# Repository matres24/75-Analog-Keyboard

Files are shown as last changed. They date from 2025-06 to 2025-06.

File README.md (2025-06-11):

# 75%-Analog-Keyboard
A custom-built mechanical keyboard featuring Hall effect sensors for analog key press detection. This project uses DRV5055A4 Hall sensors, magnets mounted in keycaps, and a CD74HC4067 multiplexer controlled by a microcontroller. Each key press is measured as a variable voltage, enabling analog input functionality. RGB LEDs (WS2812B) provide per-key lighting. This project is meant to fit into Monsgeek M1 case.

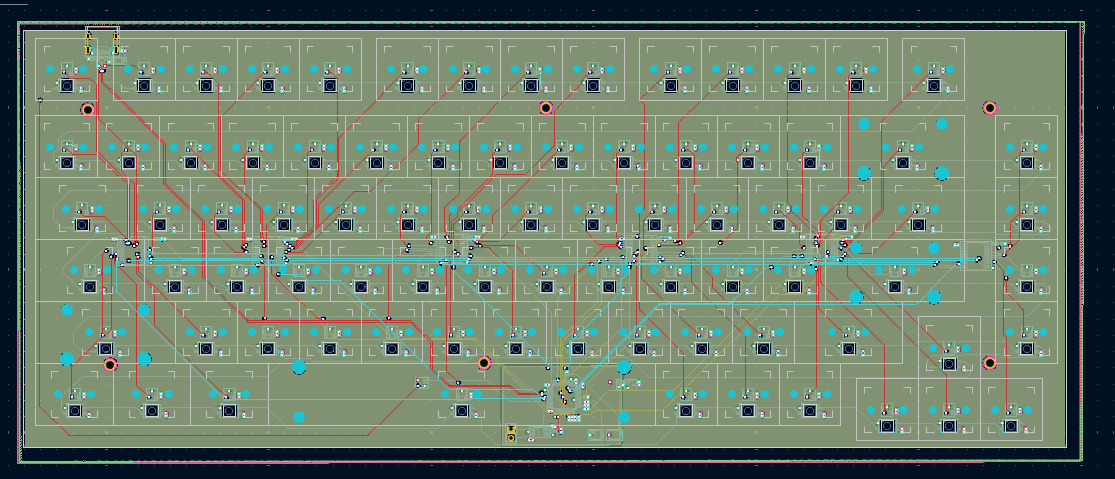
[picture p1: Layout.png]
Layout


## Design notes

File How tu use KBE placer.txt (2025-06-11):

also regarding your issue with the kbplacer plugin, a workflow that I like to use is:
use hierarchial sheets, one for each sensor
load in one of the footprints to kbplacer
disable diode auto-placement, disable auto-routing, remove "additional elements"
run the plugin
route the first sensor to its decoupling capacitors
use the "replicate layouts" plugin to replicate the placement of the remaining components and the routing

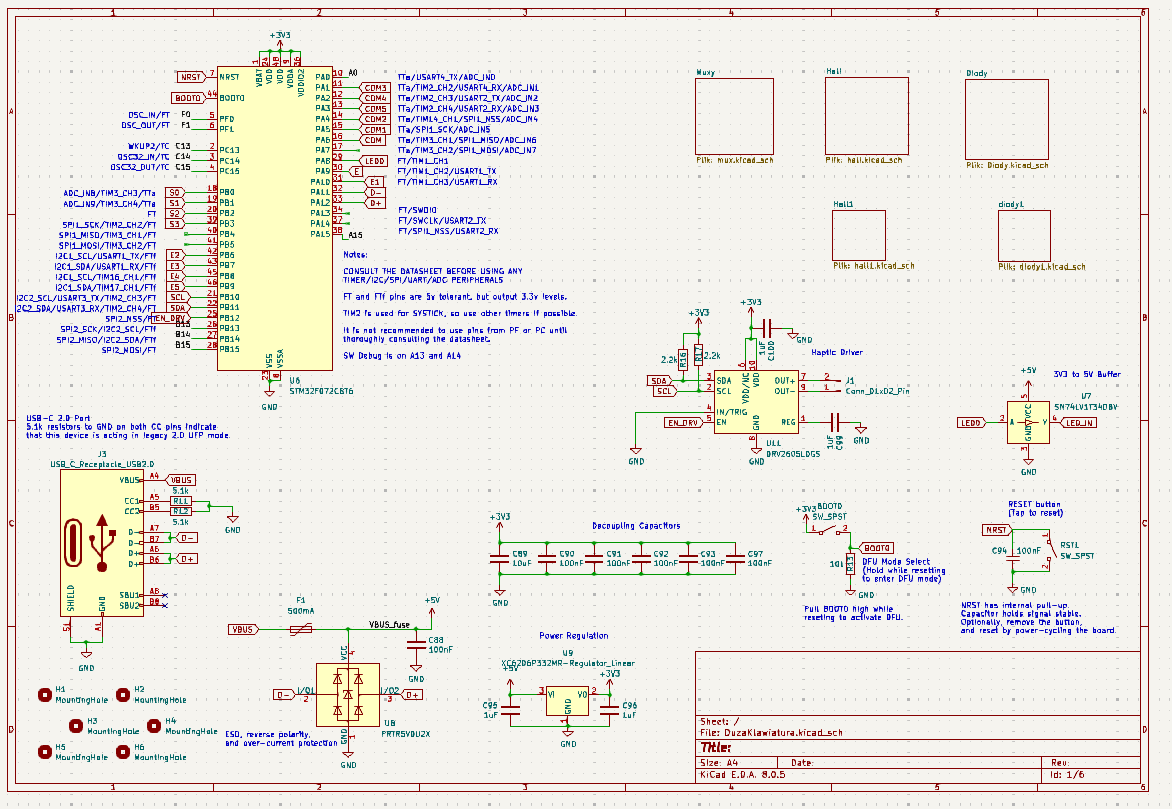
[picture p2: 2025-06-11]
Schematic.png

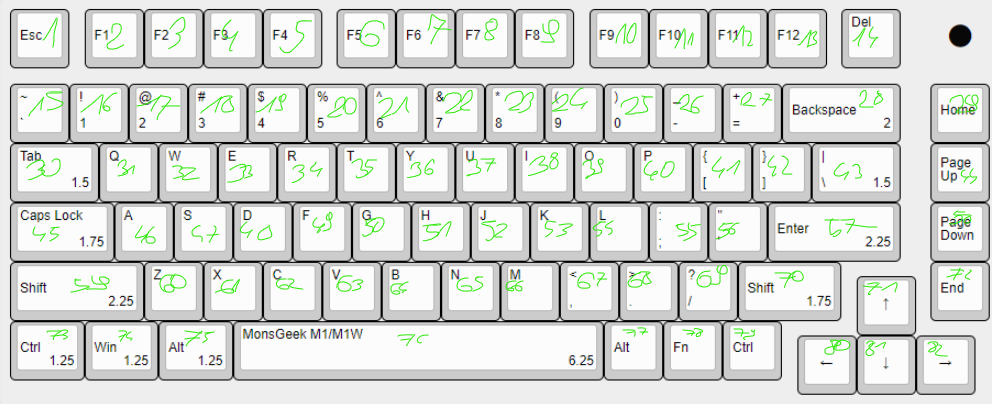
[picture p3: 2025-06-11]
Keylayout.png

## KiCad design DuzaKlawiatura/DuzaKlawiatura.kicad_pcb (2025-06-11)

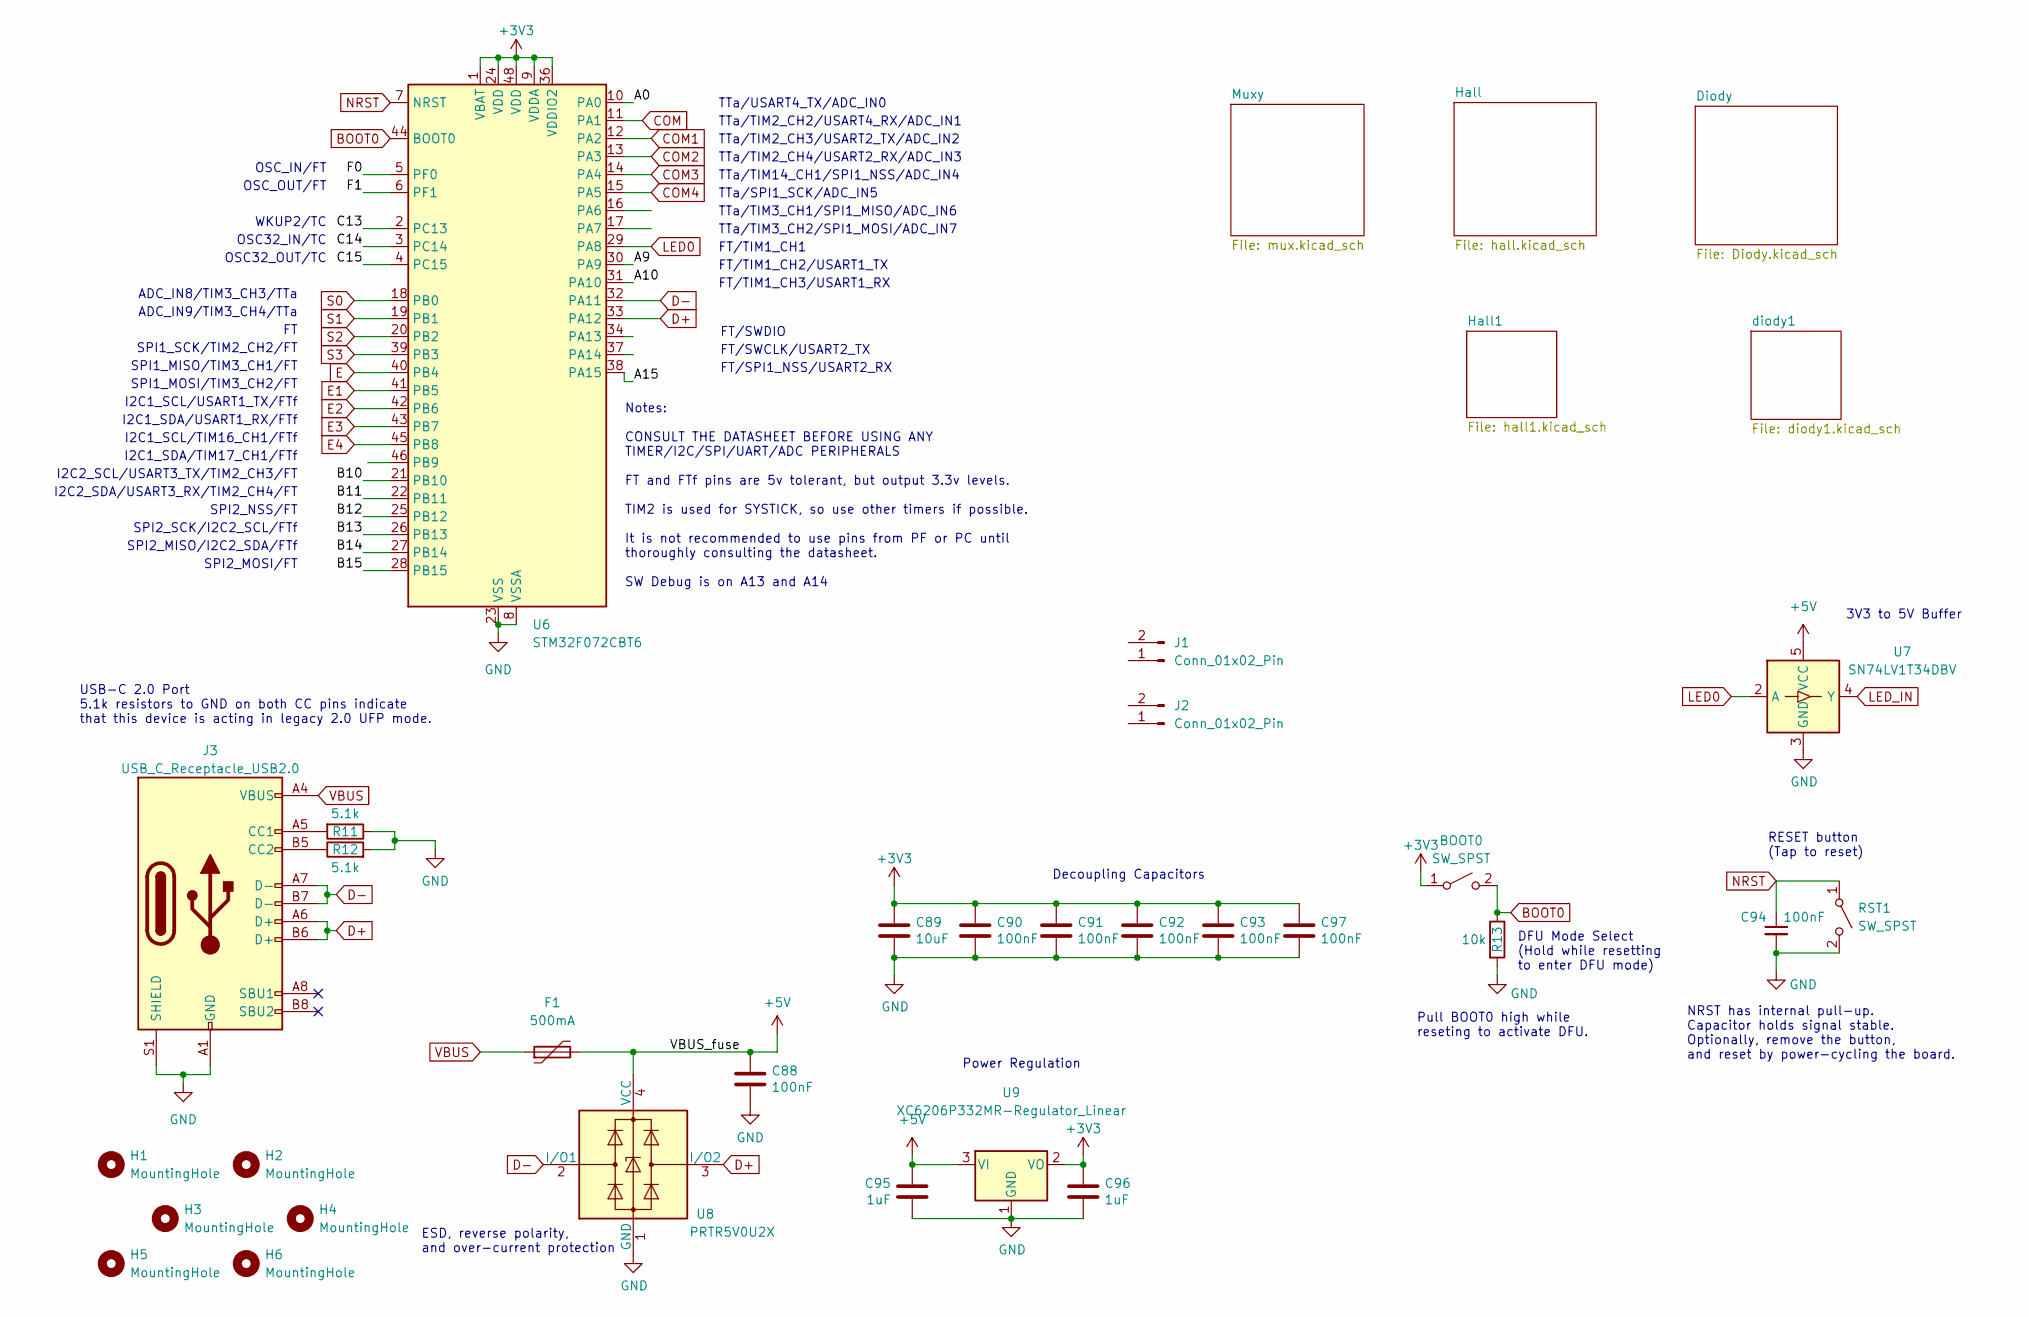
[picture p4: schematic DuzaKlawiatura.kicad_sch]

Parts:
BOOT0: SW_SPST; SW_SPST_B3U-1000P
C88, C90, C91, C92, C93, C94, C97: 100nF; C_0402_1005Metric; LCSC C307331
C89: 10uF; C_0603_1608Metric; LCSC C307331
C95, C96: 1uF; C_0402_1005Metric; LCSC C307331
F1: 500mA; Fuse_1206_3216Metric; LCSC C135341
H1, H2, H3, H4, H5, H6: MountingHole; MountingHole_2.2mm_M2_ISO7380_Pad
J1, J2: Conn_01x02_Pin; MountingHole_2.2mm_M2_ISO7380_Pad
J3: USB_C_Receptacle_USB2.0; USB_C_Receptacle_HRO_TYPE-C-31-M-12; JlcRotOffset 180
R11, R12: 5.1k; R_0402_1005Metric
R13: 10k; R_0402_1005Metric
RST1: SW_SPST; SW_SPST_B3U-1000P
U6: STM32F072CBT6; LQFP-48_7x7mm_P0.5mm; JlcRotOffset 90
U7: SN74LV1T34DBV; SOT-23-5
U8: PRTR5V0U2X; SOT-143; LCSC C2827688
U9: XC6206P332MR-Regulator_Linear; SOT-23; LCSC C5446

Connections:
+3V3: BOOT0.1 (A), C89.1, C90.1, C91.1, C92.1, C93.1, C96.1, C97.1, U6.1 (VBAT), U6.9 (VDDA), U6.24 (VDD), U6.36 (VDDIO2), U6.48 (VDD), U9.2 (VO); also elsewhere on the board
+5V: C88.1, C95.1, F1.2, U7.5 (VCC), U8.4 (VCC), U9.3 (VI); also elsewhere on the board
/A0: U6.10 (PA0)
/A9: U6.30 (PA9)
/A10: U6.31 (PA10)
/A15: U6.38 (PA15)
/B10: U6.21 (PB10)
/B11: U6.22 (PB11)
/B12: U6.25 (PB12)
/B13: U6.26 (PB13)
/B14: U6.27 (PB14)
/B15: U6.28 (PB15)
/C13: U6.2 (PC13)
/C14: U6.3 (PC14)
/C15: U6.4 (PC15)
/F0: U6.5 (PF0)
/F1: U6.6 (PF1)
BOOT0: BOOT0.2 (B), R13.1, U6.44 (BOOT0); also elsewhere on the board
COM: U6.11 (PA1); also elsewhere on the board
COM1: U6.12 (PA2); also elsewhere on the board
COM2: U6.13 (PA3); also elsewhere on the board
COM3: U6.14 (PA4); also elsewhere on the board
COM4: U6.15 (PA5); also elsewhere on the board
D+: J3.A6 (D+), J3.B6 (D+), U6.33 (PA12), U8.3 (I/O2)
D-: J3.A7 (D-), J3.B7 (D-), U6.32 (PA11), U8.2 (I/O1)
E: U6.40 (PB4); also elsewhere on the board
E1: U6.41 (PB5); also elsewhere on the board
E2: U6.42 (PB6); also elsewhere on the board
E3: U6.43 (PB7); also elsewhere on the board
E4: U6.45 (PB8); also elsewhere on the board
GND: C88.2, C89.2, C90.2, C91.2, C92.2, C93.2, C94.2, C95.2, C96.2, C97.2, J3.A1 (GND), J3.A12 (GND), J3.B1 (GND), J3.B12 (GND), J3.S1 (SHIELD), R11.1, R12.2, R13.2, RST1.2 (B), U6.8 (VSSA), U6.23 (VSS), U6.35 (VSS), U6.47 (VSS), U7.3 (GND), U8.1 (GND), U9.1 (GND); also elsewhere on the board
LED0: U6.29 (PA8), U7.2 (A)
LED_IN: U7.4 (Y); also elsewhere on the board
NRST: C94.1, RST1.1 (A), U6.7 (NRST)
unnamed: J3.A5 (CC1), R11.2
unnamed: J3.B5 (CC2), R12.1
S0: U6.18 (PB0); also elsewhere on the board
S1: U6.19 (PB1); also elsewhere on the board
S2: U6.20 (PB2); also elsewhere on the board
S3: U6.39 (PB3); also elsewhere on the board
VBUS: F1.1, J3.A4 (VBUS), J3.A9 (VBUS), J3.B4 (VBUS), J3.B9 (VBUS)

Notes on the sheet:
TTa/SPI1_SCK/ADC_IN5
SPI2_MOSI/FT
TTa/USART4_TX/ADC_IN0
ADC_IN9/TIM3_CH4/TTa
TTa/TIM3_CH1/SPI1_MISO/ADC_IN6
3V3 to 5V Buffer
I2C1_SDA/TIM17_CH1/FTf
WKUP2/TC
Notes: CONSULT THE DATASHEET BEFORE USING ANY TIMER/I2C/SPI/UART/ADC PERIPHERALS FT and FTf pins are 5v tolerant, but output 3.3v levels. TIM2 is used for SYSTICK, so use other timers if possible. It is not recommended to use pins from PF or PC until thoroughly consulting the datasheet. SW Debug is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
TTa/TIM2_CH3/USART2_TX/ADC_IN2
I2C2_SDA/USART3_RX/TIM2_CH4/FT
SPI2_NSS/FT
TTa/TIM3_CH2/SPI1_MOSI/ADC_IN7
SPI1_SCK/TIM2_CH2/FT
TTa/TIM2_CH2/USART4_RX/ADC_IN1
Decoupling Capacitors
FT/TIM1_CH2/USART1_TX
Pull BOOT0 high while reseting to activate DFU.
SPI2_SCK/I2C2_SCL/FTf
FT/SPI1_NSS/USART2_RX
SPI1_MISO/TIM3_CH1/FT
FT/SWDIO
ADC_IN8/TIM3_CH3/TTa
DFU Mode Select (Hold while resetting to enter DFU mode)
I2C1_SCL/TIM16_CH1/FTf
FT/TIM1_CH1
ESD, reverse polarity, and over-current protection
OSC_OUT/FT
NRST has internal pull-up. Capacitor holds signal stable. Optionally, remove the button, and reset by power-cycling the board.
I2C1_SCL/USART1_TX/FTf
I2C1_SDA/USART1_RX/FTf
SPI1_MOSI/TIM3_CH2/FT
Power Regulation
FT/TIM1_CH3/USART1_RX
USB-C 2.0 Port 5.1k resistors to GND on both CC pins indicate that this device is acting in legacy 2.0 UFP mode.
SPI2_MISO/I2C2_SDA/FTf
OSC_IN/FT
RESET button (Tap to reset)
I2C2_SCL/USART3_TX/TIM2_CH3/FT
OSC32_IN/TC

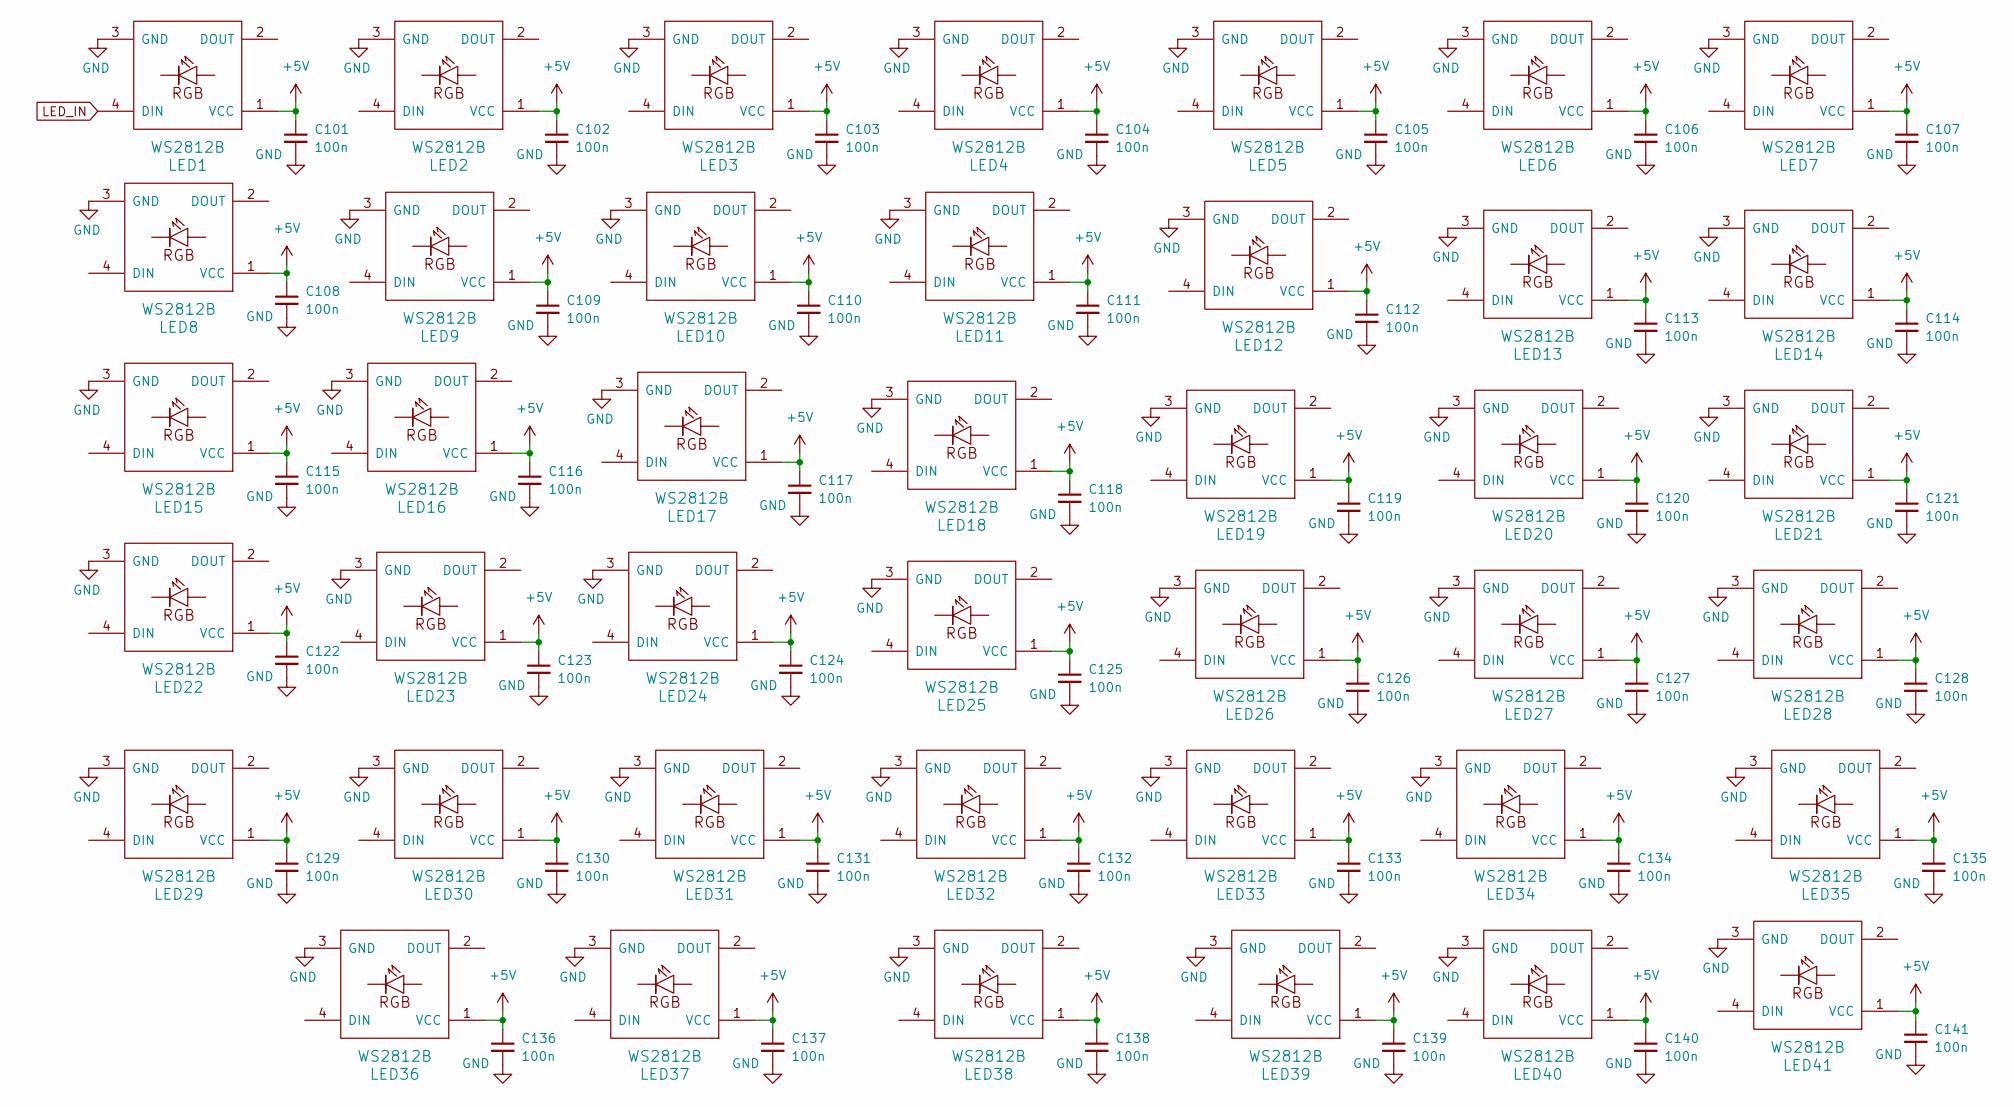
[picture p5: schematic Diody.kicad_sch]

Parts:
C101, C102, C103, C104, C105, C106, C107, C108, C109, C110, C111, C112, C113, C114, C115, C116, C117, C118, C119, C120, C121, C122, C123, C124, C125, C126, C127, C128, C129, C130, C131, C132, C133, C134, C135, C136, C137, C138, C139, C140, C141: 100n; C_0402_1005Metric
LED1, LED2, LED3, LED4, LED5, LED6, LED7, LED8, LED9, LED10, LED11, LED12, LED13, LED14, LED15, LED16, LED17, LED18, LED19, LED20, LED21, LED22, LED23, LED24, LED25, LED26, LED27, LED28, LED29, LED30, LED31, LED32, LED33, LED34, LED35, LED36, LED37, LED38, LED39, LED40, LED41: WS2812B; MX-LED_WS2812B_wide

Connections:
+5V: C101.1, C102.1, C103.1, C104.1, C105.1, C106.1, C107.1, C108.1, C109.1, C110.1, C111.1, C112.1, C113.1, C114.1, C115.1, C116.1, C117.1, C118.1, C119.1, C120.1, C121.1, C122.1, C123.1, C124.1, C125.1, C126.1, C127.1, C128.1, C129.1, C130.1, C131.1, C132.1, C133.1, C134.1, C135.1, C136.1, C137.1, C138.1, C139.1, C140.1, C141.1, LED1.1 (VCC), LED2.1 (VCC), LED3.1 (VCC), LED4.1 (VCC), LED5.1 (VCC), LED6.1 (VCC), LED7.1 (VCC), LED8.1 (VCC), LED9.1 (VCC), LED10.1 (VCC), LED11.1 (VCC), LED12.1 (VCC), LED13.1 (VCC), LED14.1 (VCC), LED15.1 (VCC), LED16.1 (VCC), LED17.1 (VCC), LED18.1 (VCC), LED19.1 (VCC), LED20.1 (VCC), LED21.1 (VCC), LED22.1 (VCC), LED23.1 (VCC), LED24.1 (VCC), LED25.1 (VCC), LED26.1 (VCC), LED27.1 (VCC), LED28.1 (VCC), LED29.1 (VCC), LED30.1 (VCC), LED31.1 (VCC), LED32.1 (VCC), LED33.1 (VCC), LED34.1 (VCC), LED35.1 (VCC), LED36.1 (VCC), LED37.1 (VCC), LED38.1 (VCC), LED39.1 (VCC), LED40.1 (VCC), LED41.1 (VCC); also elsewhere on the board
GND: C101.2, C102.2, C103.2, C104.2, C105.2, C106.2, C107.2, C108.2, C109.2, C110.2, C111.2, C112.2, C113.2, C114.2, C115.2, C116.2, C117.2, C118.2, C119.2, C120.2, C121.2, C122.2, C123.2, C124.2, C125.2, C126.2, C127.2, C128.2, C129.2, C130.2, C131.2, C132.2, C133.2, C134.2, C135.2, C136.2, C137.2, C138.2, C139.2, C140.2, C141.2, LED1.3 (GND), LED2.3 (GND), LED3.3 (GND), LED4.3 (GND), LED5.3 (GND), LED6.3 (GND), LED7.3 (GND), LED8.3 (GND), LED9.3 (GND), LED10.3 (GND), LED11.3 (GND), LED12.3 (GND), LED13.3 (GND), LED14.3 (GND), LED15.3 (GND), LED16.3 (GND), LED17.3 (GND), LED18.3 (GND), LED19.3 (GND), LED20.3 (GND), LED21.3 (GND), LED22.3 (GND), LED23.3 (GND), LED24.3 (GND), LED25.3 (GND), LED26.3 (GND), LED27.3 (GND), LED28.3 (GND), LED29.3 (GND), LED30.3 (GND), LED31.3 (GND), LED32.3 (GND), LED33.3 (GND), LED34.3 (GND), LED35.3 (GND), LED36.3 (GND), LED37.3 (GND), LED38.3 (GND), LED39.3 (GND), LED40.3 (GND), LED41.3 (GND); also elsewhere on the board
LED_IN: LED1.4 (DIN); also elsewhere on the board

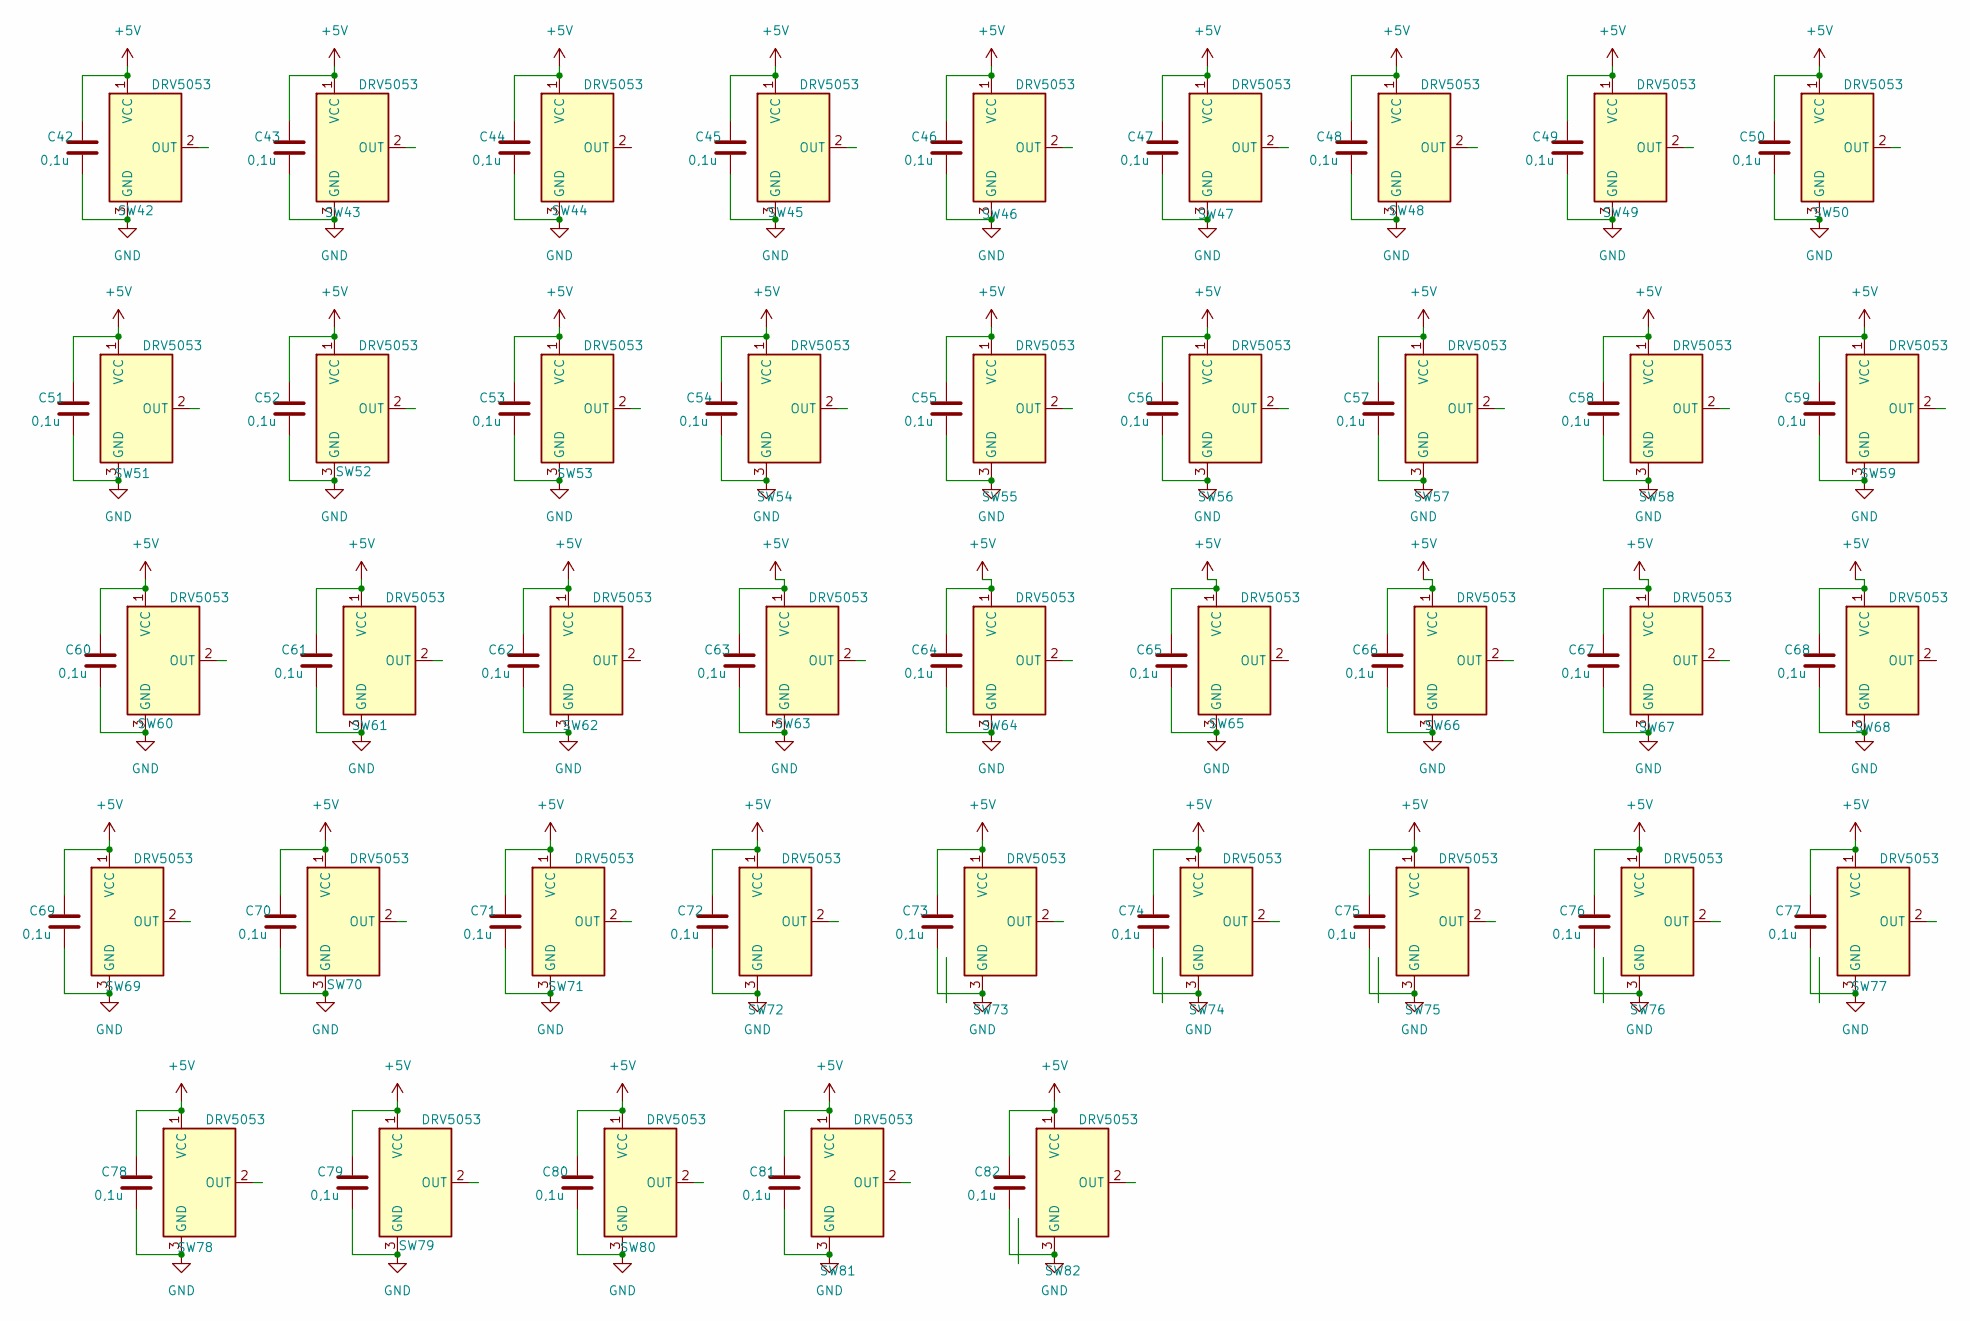
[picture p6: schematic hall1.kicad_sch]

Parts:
C42, C43, C44, C45, C46, C47, C48, C49, C50, C51, C52, C53, C54, C55, C56, C57, C58, C59, C60, C61, C62, C63, C64, C65, C66, C67, C68, C69, C70, C71, C72, C73, C74, C75, C76, C77, C78, C79, C80, C81, C82: 0,1u; C_0402_1005Metric
SW42, SW44, SW46, SW47, SW48, SW49, SW50, SW51, SW52, SW53, SW54, SW55, SW56, SW58, SW60, SW61, SW62, SW63, SW64, SW65, SW66, SW67, SW68, SW69, SW71, SW72, SW77, SW78, SW79, SW80, SW81, SW82: DRV5053; MX-Analog-1U
SW43: DRV5053; MX-Analog-1.5U
SW45, SW70: DRV5053; MX-Analog-1.75U
SW57, SW59: DRV5053; MX-Analog-2.25U
SW73, SW74, SW75: DRV5053; MX-Analog-1.25U
SW76: DRV5053; MX-Analog-6.25U-ReversedStabilizers

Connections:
+5V: C42.1, C43.1, C44.1, C45.1, C46.1, C47.1, C48.1, C49.1, C50.1, C51.1, C52.1, C53.1, C54.1, C55.1, C56.1, C57.1, C58.1, C59.1, C60.1, C61.1, C62.1, C63.1, C64.1, C65.1, C66.1, C67.1, C68.1, C69.1, C70.1, C71.1, C72.1, C73.1, C74.1, C75.1, C76.1, C77.1, C78.1, C79.1, C80.1, C81.1, C82.1, SW42.1 (VCC), SW43.1 (VCC), SW44.1 (VCC), SW45.1 (VCC), SW46.1 (VCC), SW47.1 (VCC), SW48.1 (VCC), SW49.1 (VCC), SW50.1 (VCC), SW51.1 (VCC), SW52.1 (VCC), SW53.1 (VCC), SW54.1 (VCC), SW55.1 (VCC), SW56.1 (VCC), SW57.1 (VCC), SW58.1 (VCC), SW59.1 (VCC), SW60.1 (VCC), SW61.1 (VCC), SW62.1 (VCC), SW63.1 (VCC), SW64.1 (VCC), SW65.1 (VCC), SW66.1 (VCC), SW67.1 (VCC), SW68.1 (VCC), SW69.1 (VCC), SW70.1 (VCC), SW71.1 (VCC), SW72.1 (VCC), SW73.1 (VCC), SW74.1 (VCC), SW75.1 (VCC), SW76.1 (VCC), SW77.1 (VCC), SW78.1 (VCC), SW79.1 (VCC), SW80.1 (VCC), SW81.1 (VCC), SW82.1 (VCC); also elsewhere on the board
GND: C42.2, C43.2, C44.2, C45.2, C46.2, C47.2, C48.2, C49.2, C50.2, C51.2, C52.2, C53.2, C54.2, C55.2, C56.2, C57.2, C58.2, C59.2, C60.2, C61.2, C62.2, C63.2, C64.2, C65.2, C66.2, C67.2, C68.2, C69.2, C70.2, C71.2, C72.2, C73.2, C74.2, C75.2, C76.2, C77.2, C78.2, C79.2, C80.2, C81.2, C82.2, SW42.3 (GND), SW43.3 (GND), SW44.3 (GND), SW45.3 (GND), SW46.3 (GND), SW47.3 (GND), SW48.3 (GND), SW49.3 (GND), SW50.3 (GND), SW51.3 (GND), SW52.3 (GND), SW53.3 (GND), SW54.3 (GND), SW55.3 (GND), SW56.3 (GND), SW57.3 (GND), SW58.3 (GND), SW59.3 (GND), SW60.3 (GND), SW61.3 (GND), SW62.3 (GND), SW63.3 (GND), SW64.3 (GND), SW65.3 (GND), SW66.3 (GND), SW67.3 (GND), SW68.3 (GND), SW69.3 (GND), SW70.3 (GND), SW71.3 (GND), SW72.3 (GND), SW73.3 (GND), SW74.3 (GND), SW75.3 (GND), SW76.3 (GND), SW77.3 (GND), SW78.3 (GND), SW79.3 (GND), SW80.3 (GND), SW81.3 (GND), SW82.3 (GND); also elsewhere on the board

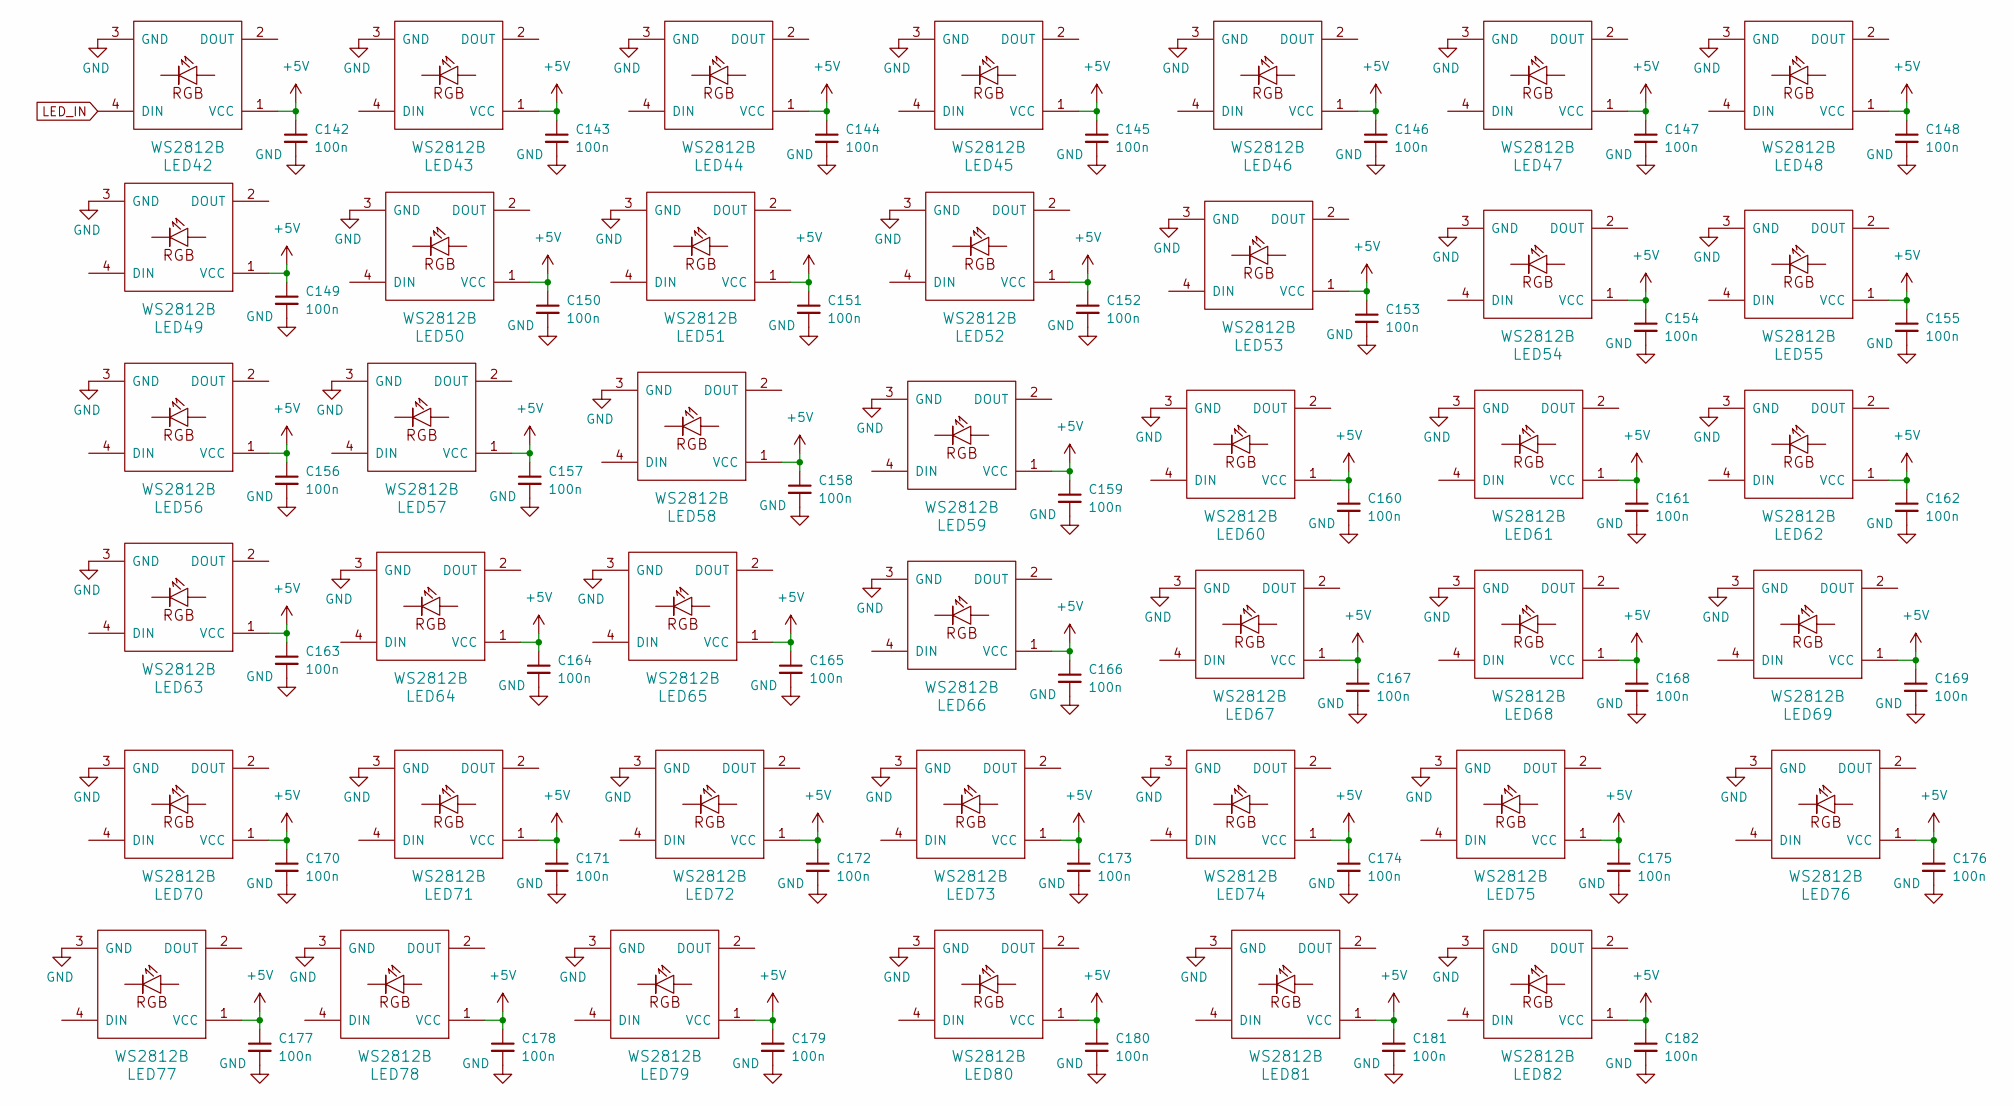
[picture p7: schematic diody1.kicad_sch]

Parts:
C142, C143, C144, C145, C146, C147, C148, C149, C150, C151, C152, C153, C154, C155, C156, C157, C158, C159, C160, C161, C162, C163, C164, C165, C166, C167, C168, C169, C170, C171, C172, C173, C174, C175, C176, C177, C178, C179, C180, C181, C182: 100n; C_0402_1005Metric
LED42, LED43, LED44, LED45, LED46, LED47, LED48, LED49, LED50, LED51, LED52, LED53, LED54, LED55, LED56, LED57, LED58, LED59, LED60, LED61, LED62, LED63, LED64, LED65, LED66, LED67, LED68, LED69, LED70, LED71, LED72, LED73, LED74, LED75, LED76, LED77, LED78, LED79, LED80, LED81, LED82: WS2812B; MX-LED_WS2812B_wide

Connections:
+5V: C142.1, C143.1, C144.1, C145.1, C146.1, C147.1, C148.1, C149.1, C150.1, C151.1, C152.1, C153.1, C154.1, C155.1, C156.1, C157.1, C158.1, C159.1, C160.1, C161.1, C162.1, C163.1, C164.1, C165.1, C166.1, C167.1, C168.1, C169.1, C170.1, C171.1, C172.1, C173.1, C174.1, C175.1, C176.1, C177.1, C178.1, C179.1, C180.1, C181.1, C182.1, LED42.1 (VCC), LED43.1 (VCC), LED44.1 (VCC), LED45.1 (VCC), LED46.1 (VCC), LED47.1 (VCC), LED48.1 (VCC), LED49.1 (VCC), LED50.1 (VCC), LED51.1 (VCC), LED52.1 (VCC), LED53.1 (VCC), LED54.1 (VCC), LED55.1 (VCC), LED56.1 (VCC), LED57.1 (VCC), LED58.1 (VCC), LED59.1 (VCC), LED60.1 (VCC), LED61.1 (VCC), LED62.1 (VCC), LED63.1 (VCC), LED64.1 (VCC), LED65.1 (VCC), LED66.1 (VCC), LED67.1 (VCC), LED68.1 (VCC), LED69.1 (VCC), LED70.1 (VCC), LED71.1 (VCC), LED72.1 (VCC), LED73.1 (VCC), LED74.1 (VCC), LED75.1 (VCC), LED76.1 (VCC), LED77.1 (VCC), LED78.1 (VCC), LED79.1 (VCC), LED80.1 (VCC), LED81.1 (VCC), LED82.1 (VCC); also elsewhere on the board
GND: C142.2, C143.2, C144.2, C145.2, C146.2, C147.2, C148.2, C149.2, C150.2, C151.2, C152.2, C153.2, C154.2, C155.2, C156.2, C157.2, C158.2, C159.2, C160.2, C161.2, C162.2, C163.2, C164.2, C165.2, C166.2, C167.2, C168.2, C169.2, C170.2, C171.2, C172.2, C173.2, C174.2, C175.2, C176.2, C177.2, C178.2, C179.2, C180.2, C181.2, C182.2, LED42.3 (GND), LED43.3 (GND), LED44.3 (GND), LED45.3 (GND), LED46.3 (GND), LED47.3 (GND), LED48.3 (GND), LED49.3 (GND), LED50.3 (GND), LED51.3 (GND), LED52.3 (GND), LED53.3 (GND), LED54.3 (GND), LED55.3 (GND), LED56.3 (GND), LED57.3 (GND), LED58.3 (GND), LED59.3 (GND), LED60.3 (GND), LED61.3 (GND), LED62.3 (GND), LED63.3 (GND), LED64.3 (GND), LED65.3 (GND), LED66.3 (GND), LED67.3 (GND), LED68.3 (GND), LED69.3 (GND), LED70.3 (GND), LED71.3 (GND), LED72.3 (GND), LED73.3 (GND), LED74.3 (GND), LED75.3 (GND), LED76.3 (GND), LED77.3 (GND), LED78.3 (GND), LED79.3 (GND), LED80.3 (GND), LED81.3 (GND), LED82.3 (GND); also elsewhere on the board
LED_IN: LED42.4 (DIN); also elsewhere on the board

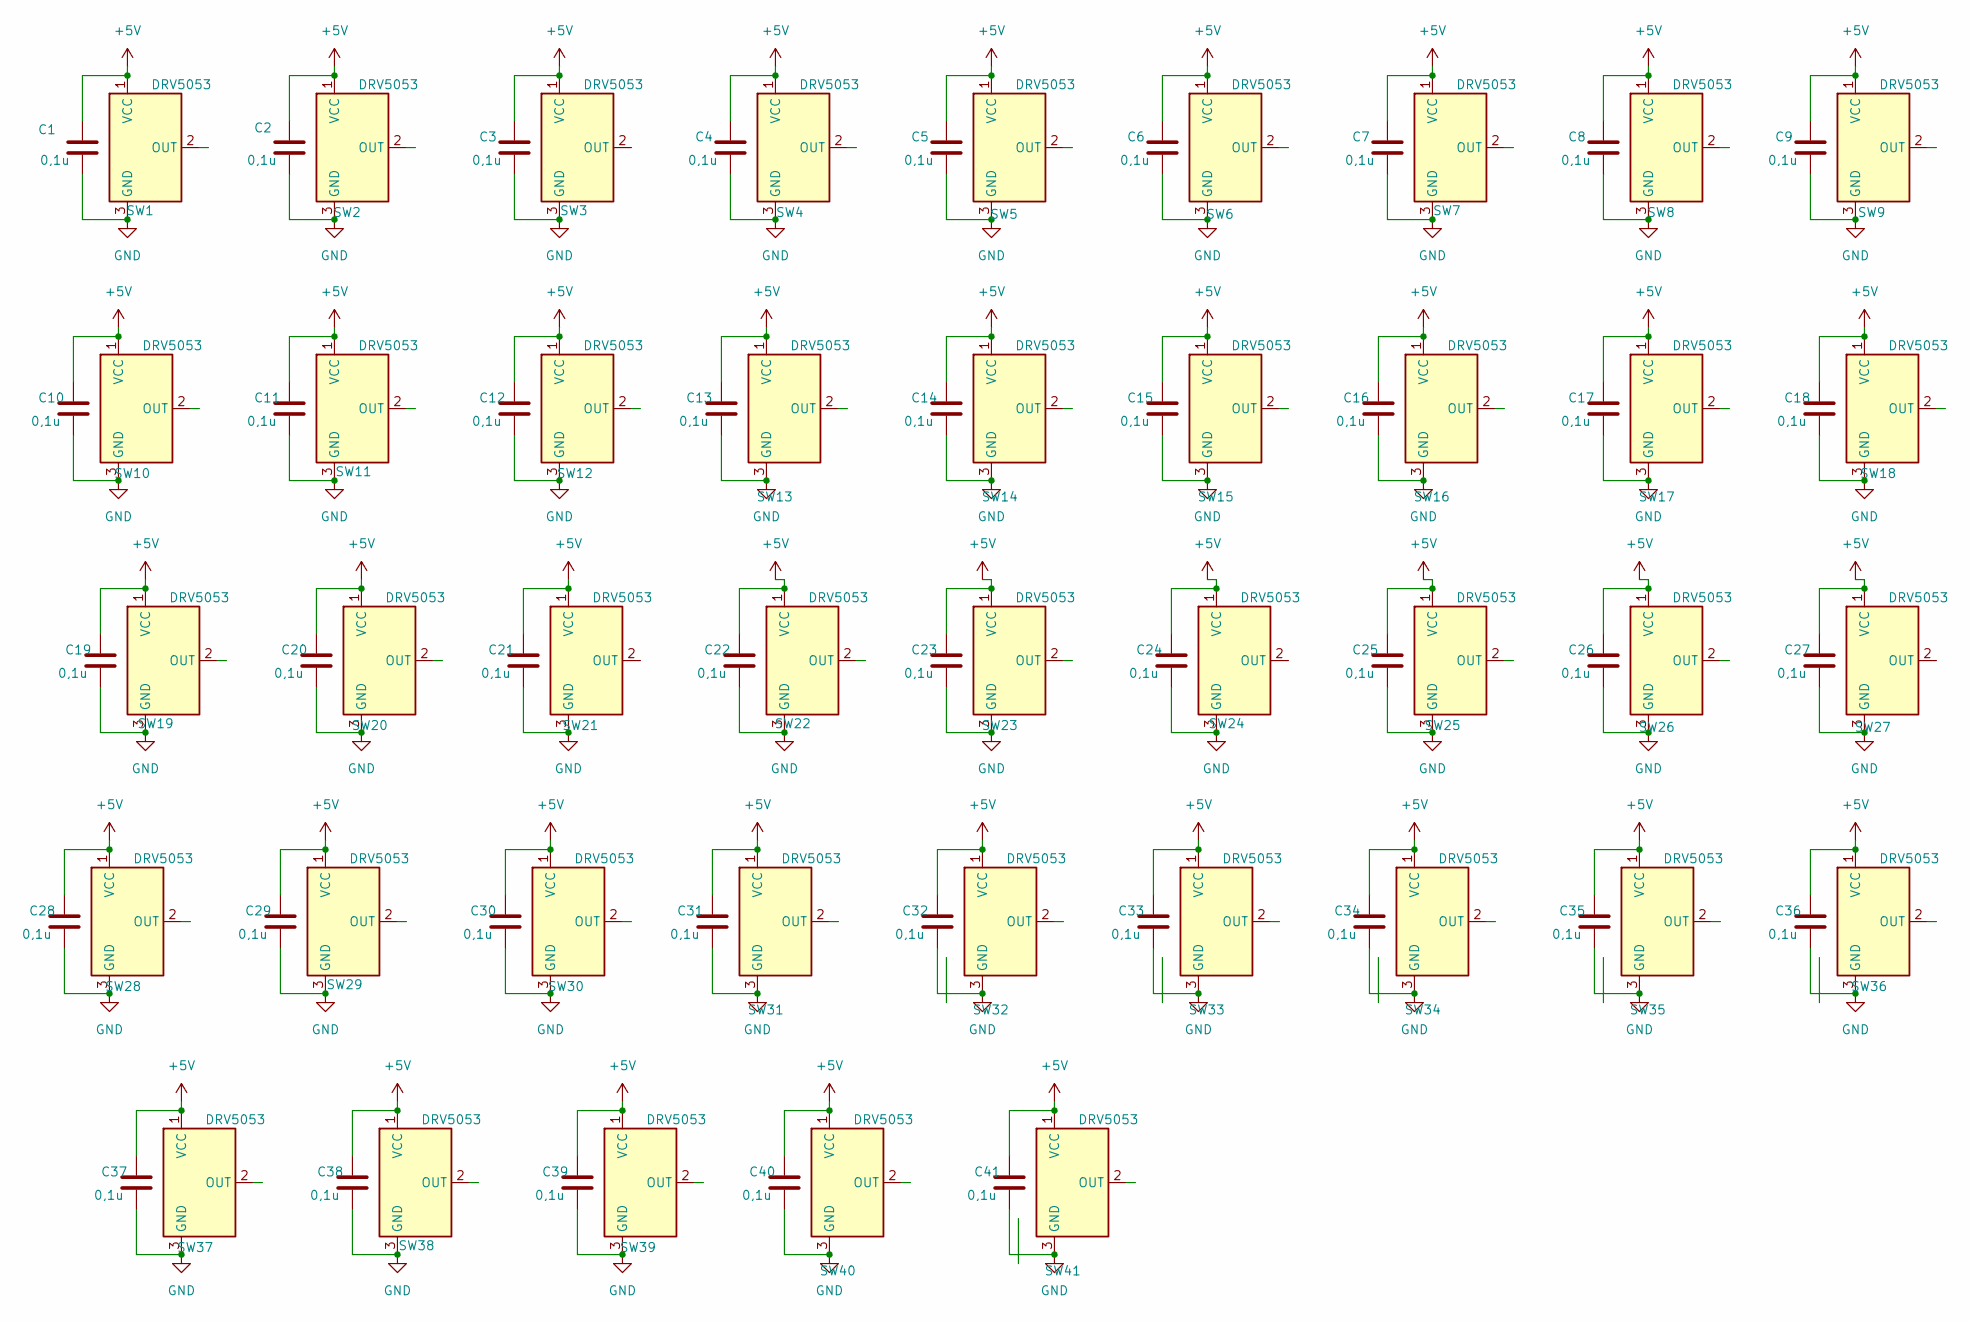
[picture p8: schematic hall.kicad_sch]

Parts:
C1, C2, C3, C4, C5, C6, C7, C8, C9, C10, C11, C12, C13, C14, C15, C16, C17, C18, C19, C20, C21, C22, C23, C24, C25, C26, C27, C28, C29, C30, C31, C32, C33, C34, C35, C36, C37, C38, C39, C40, C41: 0,1u; C_0402_1005Metric
SW1, SW2, SW3, SW4, SW5, SW6, SW7, SW8, SW9, SW10, SW11, SW12, SW13, SW14, SW15, SW16, SW17, SW18, SW19, SW20, SW21, SW22, SW23, SW24, SW25, SW26, SW27, SW29, SW31, SW32, SW33, SW34, SW35, SW36, SW37, SW38, SW39, SW40, SW41: DRV5053; MX-Analog-1U
SW28: DRV5053; MX-Analog-2U
SW30: DRV5053; MX-Analog-1.5U

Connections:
+5V: C1.1, C2.1, C3.1, C4.1, C5.1, C6.1, C7.1, C8.1, C9.1, C10.1, C11.1, C12.1, C13.1, C14.1, C15.1, C16.1, C17.1, C18.1, C19.1, C20.1, C21.1, C22.1, C23.1, C24.1, C25.1, C26.1, C27.1, C28.1, C29.1, C30.1, C31.1, C32.1, C33.1, C34.1, C35.1, C36.1, C37.1, C38.1, C39.1, C40.1, C41.1, SW1.1 (VCC), SW2.1 (VCC), SW3.1 (VCC), SW4.1 (VCC), SW5.1 (VCC), SW6.1 (VCC), SW7.1 (VCC), SW8.1 (VCC), SW9.1 (VCC), SW10.1 (VCC), SW11.1 (VCC), SW12.1 (VCC), SW13.1 (VCC), SW14.1 (VCC), SW15.1 (VCC), SW16.1 (VCC), SW17.1 (VCC), SW18.1 (VCC), SW19.1 (VCC), SW20.1 (VCC), SW21.1 (VCC), SW22.1 (VCC), SW23.1 (VCC), SW24.1 (VCC), SW25.1 (VCC), SW26.1 (VCC), SW27.1 (VCC), SW28.1 (VCC), SW29.1 (VCC), SW30.1 (VCC), SW31.1 (VCC), SW32.1 (VCC), SW33.1 (VCC), SW34.1 (VCC), SW35.1 (VCC), SW36.1 (VCC), SW37.1 (VCC), SW38.1 (VCC), SW39.1 (VCC), SW40.1 (VCC), SW41.1 (VCC); also elsewhere on the board
GND: C1.2, C2.2, C3.2, C4.2, C5.2, C6.2, C7.2, C8.2, C9.2, C10.2, C11.2, C12.2, C13.2, C14.2, C15.2, C16.2, C17.2, C18.2, C19.2, C20.2, C21.2, C22.2, C23.2, C24.2, C25.2, C26.2, C27.2, C28.2, C29.2, C30.2, C31.2, C32.2, C33.2, C34.2, C35.2, C36.2, C37.2, C38.2, C39.2, C40.2, C41.2, SW1.3 (GND), SW2.3 (GND), SW3.3 (GND), SW4.3 (GND), SW5.3 (GND), SW6.3 (GND), SW7.3 (GND), SW8.3 (GND), SW9.3 (GND), SW10.3 (GND), SW11.3 (GND), SW12.3 (GND), SW13.3 (GND), SW14.3 (GND), SW15.3 (GND), SW16.3 (GND), SW17.3 (GND), SW18.3 (GND), SW19.3 (GND), SW20.3 (GND), SW21.3 (GND), SW22.3 (GND), SW23.3 (GND), SW24.3 (GND), SW25.3 (GND), SW26.3 (GND), SW27.3 (GND), SW28.3 (GND), SW29.3 (GND), SW30.3 (GND), SW31.3 (GND), SW32.3 (GND), SW33.3 (GND), SW34.3 (GND), SW35.3 (GND), SW36.3 (GND), SW37.3 (GND), SW38.3 (GND), SW39.3 (GND), SW40.3 (GND), SW41.3 (GND); also elsewhere on the board

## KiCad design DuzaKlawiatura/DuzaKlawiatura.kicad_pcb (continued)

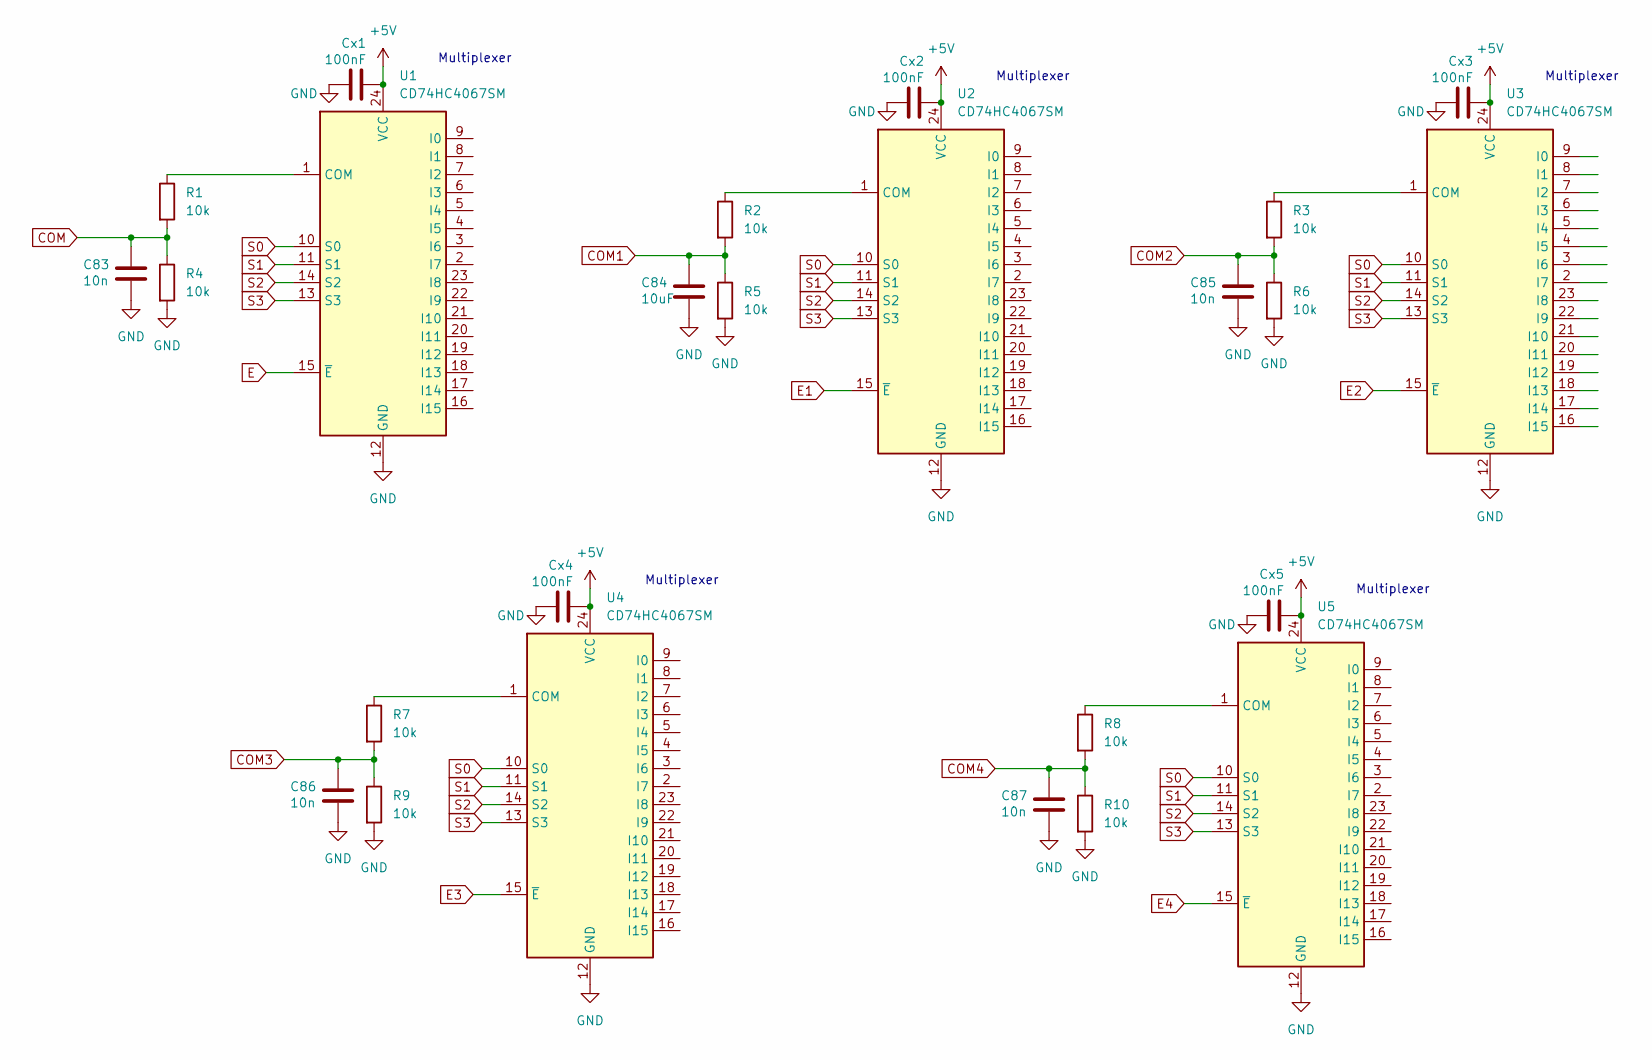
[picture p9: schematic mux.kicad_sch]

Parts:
C83, C85, C86, C87: 10n; C_0402_1005Metric
C84: 10uF; C_0402_1005Metric
Cx1, Cx2, Cx3, Cx4, Cx5: 100nF; C_0402_1005Metric; LCSC C307331
R1, R2, R3, R4, R5, R6, R7, R8, R9, R10: 10k; R_0402_1005Metric
U1, U2, U3, U4, U5: CD74HC4067SM; SSOP-24_5.3x8.2mm_P0.65mm

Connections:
+5V: Cx1.2, Cx2.2, Cx3.2, Cx4.2, Cx5.2, U1.24 (VCC), U2.24 (VCC), U3.24 (VCC), U4.24 (VCC), U5.24 (VCC); also elsewhere on the board
COM: C83.1, R1.2, R4.1; also elsewhere on the board
COM1: C84.1, R2.2, R5.1; also elsewhere on the board
COM2: C85.1, R3.2, R6.1; also elsewhere on the board
COM3: C86.1, R7.2, R9.1; also elsewhere on the board
COM4: C87.1, R8.2, R10.1; also elsewhere on the board
E: U1.15 (~E); also elsewhere on the board
E1: U2.15 (~E); also elsewhere on the board
E2: U3.15 (~E); also elsewhere on the board
E3: U4.15 (~E); also elsewhere on the board
E4: U5.15 (~E); also elsewhere on the board
GND: C83.2, C84.2, C85.2, C86.2, C87.2, Cx1.1, Cx2.1, Cx3.1, Cx4.1, Cx5.1, R4.2, R5.2, R6.2, R9.2, R10.2, U1.12 (GND), U2.12 (GND), U3.12 (GND), U4.12 (GND), U5.12 (GND); also elsewhere on the board
unnamed: R1.1, U1.1 (COM)
unnamed: R2.1, U2.1 (COM)
unnamed: R3.1, U3.1 (COM)
unnamed: R7.1, U4.1 (COM)
unnamed: R8.1, U5.1 (COM)
S0: U1.10 (S0), U2.10 (S0), U3.10 (S0), U4.10 (S0), U5.10 (S0); also elsewhere on the board
S1: U1.11 (S1), U2.11 (S1), U3.11 (S1), U4.11 (S1), U5.11 (S1); also elsewhere on the board
S2: U1.14 (S2), U2.14 (S2), U3.14 (S2), U4.14 (S2), U5.14 (S2); also elsewhere on the board
S3: U1.13 (S3), U2.13 (S3), U3.13 (S3), U4.13 (S3), U5.13 (S3); also elsewhere on the board

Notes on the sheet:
Multiplexer

Board: 2 copper layers, 386 parts (208 on the bottom side), 31 nets, no tracks yet.

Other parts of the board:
BOOT1: SW_SPST; SW_SPST_B3U-1000P
C98, C99, C100: 0,1u; C_0402_1005Metric

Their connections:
+3V3: BOOT1.1 (A); also elsewhere on the board
+5V: C98.1, C99.1, C100.1; also elsewhere on the board
BOOT0: BOOT1.2 (B); also elsewhere on the board
GND: C98.2, C99.2, C100.2; also elsewhere on the board

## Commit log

2025-06-11 Pliki KiCad
    [Diody.kicad_sch, DuzaKlawiatura.kicad_pcb, DuzaKlawiatura.kicad_sch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]
2025-06-11 Added photos of layout and schematic, updated Kicad files.
    [Diody.kicad_sch, DuzaKlawiatura.kicad_sch, diody1.kicad_sch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]
